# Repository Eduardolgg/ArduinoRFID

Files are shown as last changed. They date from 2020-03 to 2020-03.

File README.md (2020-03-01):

# ArduinoRFID
RFID authentication with Arduino.

# Domoticz

## Configuration

1. Set a static IP for the ESP-01s on your router.

2. Create the user variables rfid_id y rfid_ids_valid.
* rfid_id will contain the last tag sent to Domoticz.
* rfid_ids_valid will contain all valid tags.

3 Create the scripts using those found in the Domoticz_scripts directory, replace in the scripts the static IP associated with your wifi module.

## Add a new Tag

1. Scan the tag.

2. Go to Domoticz log and copy the ID.

3. Enter it in the user variable rfid_ids_valid by separating each Id by : (Ej: IDTAG1:IDTAG2:...).

# Arduino

1. Remember to replace the Domoticz IP and the user variable ID rfid_id in the code.

2. Flash Arduino and ESP-01s

3. Make the circuit using the included schemes

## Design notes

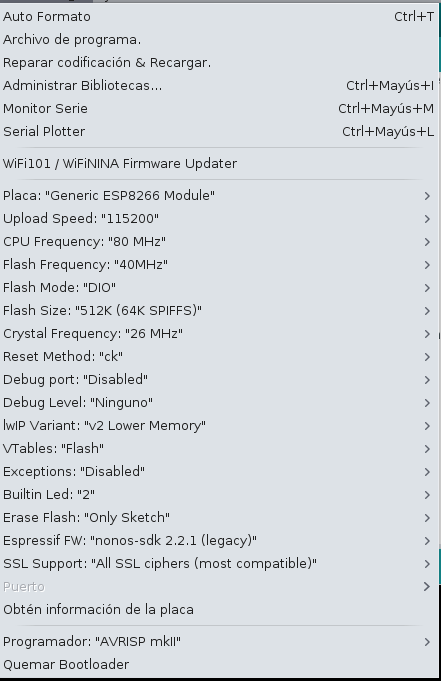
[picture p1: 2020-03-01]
ArduinoIDE_config.png

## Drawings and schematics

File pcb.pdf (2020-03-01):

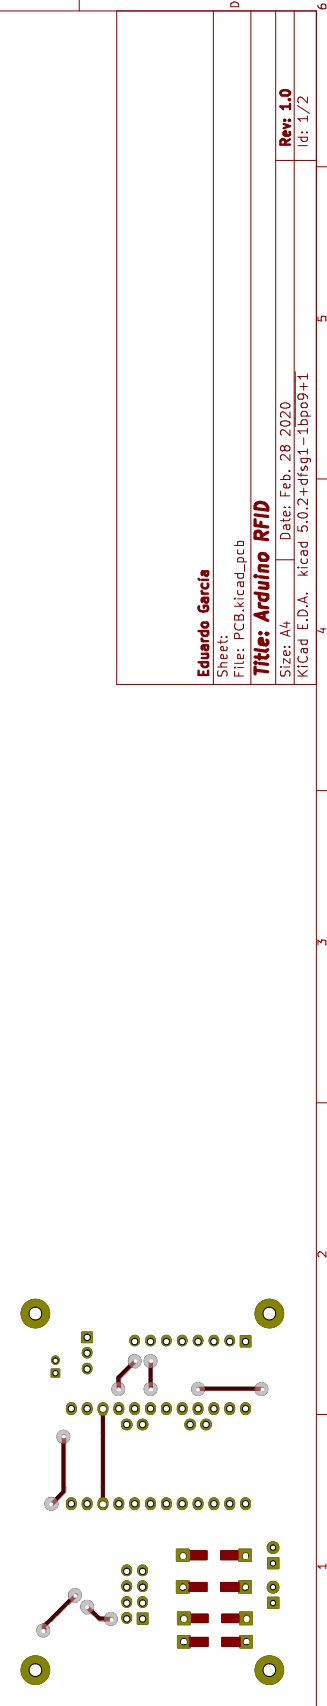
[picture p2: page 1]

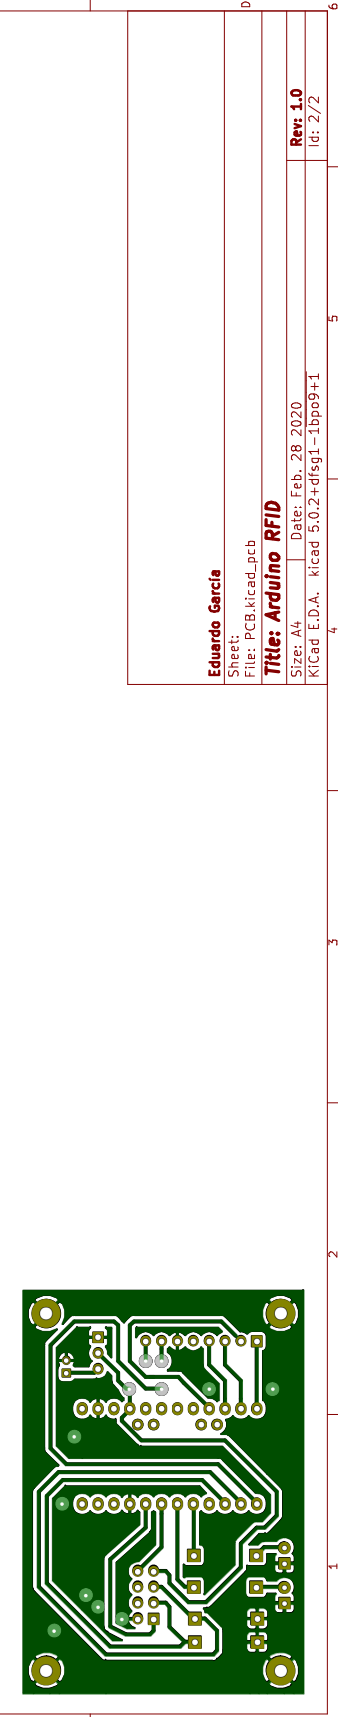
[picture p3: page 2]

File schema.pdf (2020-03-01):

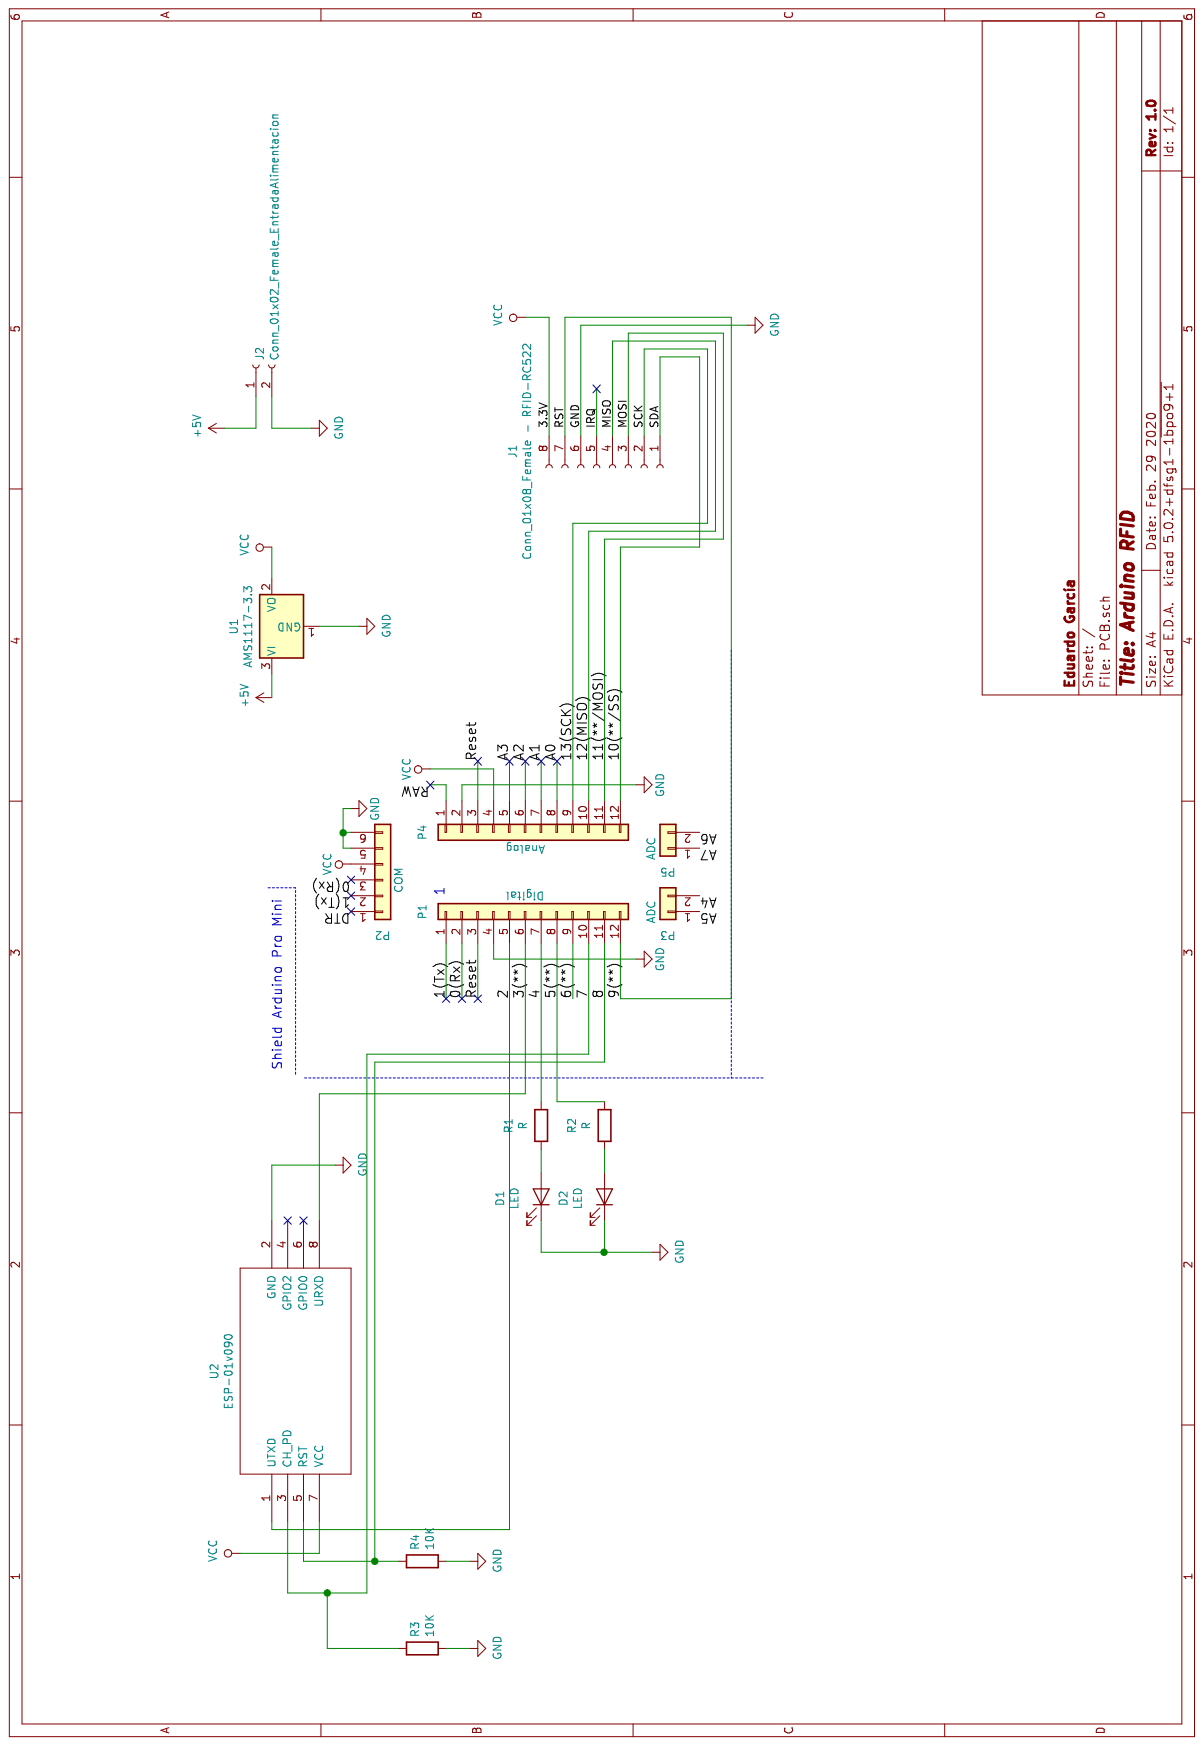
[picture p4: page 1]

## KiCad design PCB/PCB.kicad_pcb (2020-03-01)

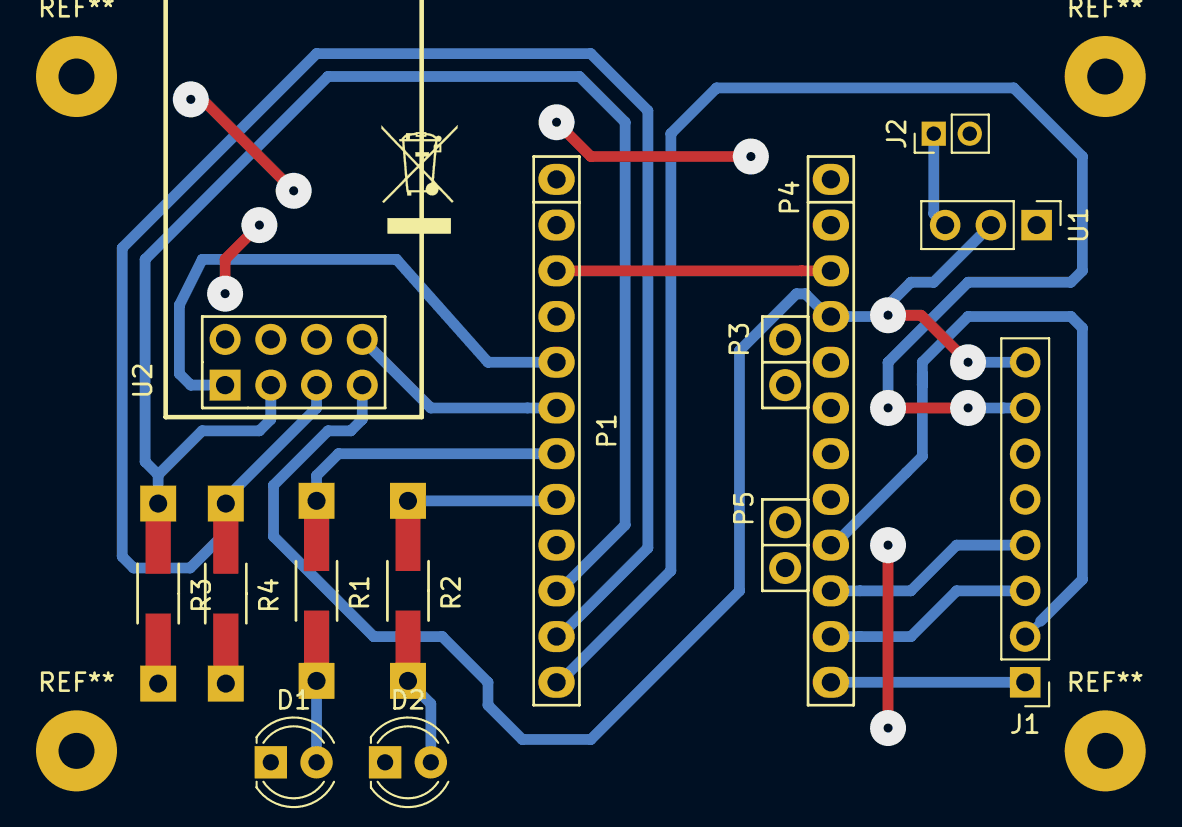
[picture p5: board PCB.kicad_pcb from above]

Board: 2 copper layers, 14 parts (0 on the bottom side), 17 nets.

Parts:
D1, D2: LED; LED_D4.0mm
J1: Conn_01x08_Female - RFID-RC522; Socket_Strip_Straight_1x08_Pitch2.54mm
J2: Conn_01x02_Female_EntradaAlimentacion; Socket_Strip_Straight_1x02_Pitch2.00mm
P1: Digital; Socket_Strip_Arduino_1x12
P3, P5: ADC; Socket_Strip_Arduino_1x02
P4: Analog; Socket_Strip_Arduino_1x12
R1, R2: R; Resistor_SMD+THTuniversal_1206_RM10_HandSoldering
R3, R4: 10K; Resistor_SMD+THTuniversal_1206_RM10_HandSoldering
U1: AMS1117-3.3; Socket_Strip_Straight_1x03_Pitch2.54mm
U2: ESP-01v090; ESP-01

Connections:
+5V: J2.1, U1.3
/2: P1.5, U2.1
/3(**): P1.6, U2.8
/4: P1.7, R1.1
/5(**): P1.8, R2.1
/7: P1.10, R3.1, U2.3
/8: P1.11, R4.1, U2.5
/9(**): J1.7, P1.12
/10(**/SS): J1.1, P4.12
/11(**/MOSI): J1.3, P4.11
/12(MISO): J1.4, P4.10
/13(SCK): J1.2, P4.9
/Reset: P1.3, P4.3
GND: D1.1, D2.1, J1.6, J2.2, P1.4, P4.2, R3.2, R4.2, U1.1, U2.2
unnamed: D1.2, R1.2
unnamed: D2.2, R2.2
VCC: J1.8, P4.4, U1.2, U2.7

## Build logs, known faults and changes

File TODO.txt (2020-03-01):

* HTTPS.
* Autentication.
* Change security status to Arm with tag.
* Battery.
* Accept multiple RFID modules
* Replace Domoticz user variables, create a new hardware in Domoticz.

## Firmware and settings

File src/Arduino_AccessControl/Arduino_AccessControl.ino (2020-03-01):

/*
 * This program is distributed in the hope that it will be useful,
 * but WITHOUT ANY WARRANTY.
 */


/*
   Typical pin layout used:
   -----------------------------------------------------------------------------------------
               MFRC522      Arduino       Arduino   Arduino  Arduino    Arduino          Arduino
               Reader/PCD   Uno/101       Mega      Nano v3  Pro Mini   Leonardo/Micro   Pro Micro
   Signal      Pin          Pin           Pin       Pin      Pin        Pin              Pin
   -----------------------------------------------------------------------------------------
   RST/Reset   RST          9             5         D9       D9         RESET/ICSP-5     RST
   SPI SS      SDA(SS)      10            53        D10      D10        10               10
   SPI MOSI    MOSI         11 / ICSP-4   51        D11      D11        ICSP-4           16
   SPI MISO    MISO         12 / ICSP-1   50        D12      D12        ICSP-1           14
   SPI SCK     SCK          13 / ICSP-3   52        D13      D13        ICSP-3           15
*/

#include <SPI.h>                // RC522 Module uses SPI protocol
#include <MFRC522.h>            // Library for Mifare RC522 Devices
#include <SoftwareSerial.h>
SoftwareSerial softSerial(2,3); // RX, TX
String inputString = "";        // A String to hold incoming data
bool stringComplete = false;    // whether the string is complete

const uint32_t baud = 9600;

#define ARM_LED_PIN 4
#define DISARM_LED_PIN 5

#define RESET_WIFI_PIN 8
#define ENABLE_WIFI_PIN 7

#define UNDEFINED 0
#define ARM 1
#define DISARM 2
int segMode = UNDEFINED; // Alarm status Armed/Disarmed.

uint8_t successRead;     // Variable integer to keep if we have Successful Read from Reader

byte readCard[4];        // Stores scanned ID read from RFID Module
String tag;              // Stores scanned ID read from RFID Module as String

// Create MFRC522 instance.
#define SS_PIN 10
#define RST_PIN 9
MFRC522 mfrc522(SS_PIN, RST_PIN);

///////////////////////////////////////// Setup ///////////////////////////////////
void setup() {

  // Pin config;
  pinMode(ARM_LED_PIN, OUTPUT);
  pinMode(DISARM_LED_PIN, OUTPUT);
  pinMode(RESET_WIFI_PIN, OUTPUT);
  pinMode(ENABLE_WIFI_PIN, OUTPUT);

  // Initial led mode;
  digitalWrite(ENABLE_WIFI_PIN, LOW);
  digitalWrite(RESET_WIFI_PIN, LOW);
  digitalWrite(ARM_LED_PIN, LOW);  
  digitalWrite(DISARM_LED_PIN, LOW);


  //Protocol Configuration
  Serial.begin(baud);      // Initialize serial communications with PC
  softSerial.begin(baud);  // Inicializs serial cominications with ESP-01s
  SPI.begin();             // MFRC522 Hardware uses SPI protocol
  mfrc522.PCD_Init();      // Initialize MFRC522 Hardware

  //If you set Antenna Gain to Max it will increase reading distance
  //mfrc522.PCD_SetAntennaGain(mfrc522.RxGain_max);

  Serial.println(F("Access Control Example v0.1"));   // For debugging purposes
  ShowReaderDetails();  // Show details of PCD - MFRC522 Card Reader details

  Serial.println(F("Waiting for Wifi module"));  
  digitalWrite(ENABLE_WIFI_PIN, HIGH);
  digitalWrite(RESET_WIFI_PIN, HIGH);
  while(!stringComplete) {
    leerComando();
    if (stringComplete) {
      if (inputString.indexOf("Wifi module started") >= 0)
        goto WifiConected;
      Serial.println(inputString);
      inputString = "";
      stringComplete = false;
    }
    Serial.print(".");
  }
WifiConected:
  Serial.println(inputString);
  inputString = "";
  stringComplete = false;
  // Tell wifi module get security status.
  softSerial.write("GetSecurityStatus\n");

  Serial.println(F("-------------------"));
  Serial.println(F("Everything is ready"));
  Serial.println(F("Waiting PICCs to be scanned"));
}


///////////////////////////////////////// Main Loop ///////////////////////////////////
void loop () {
  do {
    successRead = getID();  // sets successRead to 1 when we get read from reader otherwise 0    
    setStatusLeds();
    leerComando();
    if (stringComplete) {
      ejecutarComando(inputString);
      inputString = "";
      stringComplete = false;
    }
  } while (!successRead);   //the program will not go further while you are not getting a successful read
  sendTag();
}

void sendTag() {
  softSerial.write(String(tag + "\n").c_str());
}

void leerComando() {
  while (softSerial.available()) {
    // get the new byte:
    char inChar = (char)softSerial.read();
    // if the incoming character is a newline, set a flag so the main loop can
    // do something about it:
    if (inChar == '\n')
      stringComplete = true;
    else
      // add it to the inputString: I don't want a \n at end.
      inputString += inChar;
  }
}

void ejecutarComando(String comando) {
  if (comando == String("Disarm")) {
    segMode = DISARM;
  } else if (comando == String("Armed")) {
    segMode = ARM;
  } else
    Serial.write(String(comando + "\n").c_str());
}

void setStatusLeds() {
  if (segMode == DISARM) {
    digitalWrite(DISARM_LED_PIN, HIGH);
    digitalWrite(ARM_LED_PIN, LOW);
  } else if (segMode == ARM) {
    digitalWrite(DISARM_LED_PIN, LOW);
    digitalWrite(ARM_LED_PIN, HIGH);
  } else {
    digitalWrite(DISARM_LED_PIN, HIGH);
    digitalWrite(ARM_LED_PIN, HIGH);
  }
}

///////////////////////////////////////// Get PICC's UID ///////////////////////////////////
uint8_t getID() {
  // Getting ready for Reading PICCs
  if ( ! mfrc522.PICC_IsNewCardPresent()) { //If a new PICC placed to RFID reader continue
    return 0;
  }
  if ( ! mfrc522.PICC_ReadCardSerial()) {   //Since a PICC placed get Serial and continue
    return 0;
  }
  // There are Mifare PICCs which have 4 byte or 7 byte UID care if you use 7 byte PICC
  // I think we should assume every PICC as they have 4 byte UID
  // Until we support 7 byte PICCs
  Serial.println(F("Scanned PICC's UID:"));
  for ( uint8_t i = 0; i < 4; i++) {  //
    readCard[i] = mfrc522.uid.uidByte[i];
    Serial.print(readCard[i], HEX);
  }
  Serial.println("");
  mfrc522.PICC_HaltA(); // Stop reading

  char str[32] = "";
  array_to_string(readCard, 4, str);
  tag = String(str);

  return 1;
}

void ShowReaderDetails() {
  // Get the MFRC522 software version
  byte v = mfrc522.PCD_ReadRegister(mfrc522.VersionReg);
  Serial.print(F("MFRC522 Software Version: 0x"));
  Serial.print(v, HEX);
  if (v == 0x91)
    Serial.print(F(" = v1.0"));
  else if (v == 0x92)
    Serial.print(F(" = v2.0"));
  else
    Serial.print(F(" (unknown),probably a chinese clone?"));
  Serial.println("");
  // When 0x00 or 0xFF is returned, communication probably failed
  if ((v == 0x00) || (v == 0xFF)) {
    Serial.println(F("WARNING: Communication failure, is the MFRC522 properly connected?"));
    Serial.println(F("SYSTEM HALTED: Check connections."));
    while (true); // do not go further
  }
}

void array_to_string(byte array[], unsigned int len, char buffer[])
{
    for (unsigned int i = 0; i < len; i++)
    {
        byte nib1 = (array[i] >> 4) & 0x0F;
        byte nib2 = (array[i] >> 0) & 0x0F;
        buffer[i*2+0] = nib1  < 0xA ? '0' + nib1  : 'A' + nib1  - 0xA;
        buffer[i*2+1] = nib2  < 0xA ? '0' + nib2  : 'A' + nib2  - 0xA;
    }
    buffer[len*2] = '\0';
}

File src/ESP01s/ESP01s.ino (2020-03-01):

/*
 * This program is distributed in the hope that it will be useful,
 * but WITHOUT ANY WARRANTY.
 */


#include <ESP8266WiFi.h>
#include <ESP8266WiFiMulti.h>
#include <WiFiClient.h>
#include <ESP8266WebServer.h>
#include <ESP8266mDNS.h>
#include <ESP8266HTTPClient.h>

#ifndef STASSID
#define STASSID "Your_wifi_SSID_here"
#define STAPSK  "Your_wifi_password_here"
#endif

const uint32_t baud = 9600;

const char* ssid = STASSID;
const char* password = STAPSK;

ESP8266WebServer server(80);
ESP8266WiFiMulti WiFiMulti;

String inputString = "";         // A String to hold incoming data
bool stringComplete = false;     // whether the string is complete

void handleRoot() {
  server.send(200, "text/plain", "ok");
  if (server.arg("command").equals("Disarm"))
    Serial.printf("Disarm\n");
  if (server.arg("command").equals("Armed"))
    Serial.printf("Armed\n");
}

void handleNotFound() {
  String message = "File Not Found\n\n";
  message += "URI: ";
  message += server.uri();
  message += "\nMethod: ";
  message += (server.method() == HTTP_GET) ? "GET" : "POST";
  message += "\nArguments: ";
  message += server.args();
  message += "\n";
  for (uint8_t i = 0; i < server.args(); i++) {
    message += " " + server.argName(i) + ": " + server.arg(i) + "\n";
  }
  server.send(404, "text/plain", message);
}

void setup(void) {
  Serial.begin(baud);
  WiFi.mode(WIFI_STA);
  //WiFi.begin(ssid, password);
  WiFiMulti.addAP(ssid, password);
  Serial.println("");

  // Wait for connection
  while (WiFiMulti.run() != WL_CONNECTED) {
    delay(500);
    Serial.print(".");
  }
  Serial.println("");
  Serial.print("Connected to ");
  Serial.println(ssid);
  Serial.print("IP address: ");
  Serial.println(WiFi.localIP());

  if (MDNS.begin("esp8266")) {
    Serial.println("MDNS responder started");
  }

  server.on("/", handleRoot);

  /*server.on("/inline", []() {
    server.send(200, "text/plain", "this works as well");
  });*/

  server.onNotFound(handleNotFound);

  server.begin();
  Serial.println("Wifi module started");
}

void leerComando() {
  while (Serial.available()) {
    // Get the new byte:
    char inChar = (char)Serial.read();    
    // Serial.printf("leerComando: leido %c comando: %s\n", inChar, inputString.c_str());
    // if the incoming character is a newline, set a flag so the main loop can
    // do something about it:
    if (inChar == '\n')
      stringComplete = true;
    else
      // add it to the inputString: I don't want a \n at end.
      inputString += inChar;
  }
}

/**
 * Send the RFID Tag detected to verify in the control unit.
 */
void ejecutarComando(String command) {
  HTTPClient http;
  WiFiClient client;
  String url = "http://192.168.xxx.xxx/json.htm?type=command&param=updateuservariable&idx=18&vname=rfid_id&vtype=2&vvalue=";
  url.concat(command);
  url.trim();

  if (WiFiMulti.run() != WL_CONNECTED) {
    Serial.printf("Waiting for wifi to reconnect");
    while ((WiFiMulti.run() != WL_CONNECTED))
      Serial.print(".");
    Serial.println("");
  }

  Serial.printf("Run command: dest url: %s\n", url.c_str());
  if (http.begin(client, url)) {
    int httpCode = http.GET();
    if (httpCode > 0) {
      if (httpCode == HTTP_CODE_OK || httpCode == HTTP_CODE_MOVED_PERMANENTLY)
        Serial.printf("ejecutarComando: Tag %s send success \n", command.c_str());
      else {
        Serial.printf("ejecutarComando: Call error %i\n  response: ", httpCode);
        //String payload = http.getString();
        //Serial.println(payload);
      }
    } else
      Serial.printf("ejecutarComando: [HTTP] GET... failed, error: %s\n", http.errorToString(httpCode).c_str()); 
    http.end();
  } else
    Serial.printf("ejecutarComando: [HTTP} Unable to connect\n");
}

void loop(void) {
  server.handleClient();
  MDNS.update();
  leerComando();
  if (stringComplete) {
    ejecutarComando(inputString);
    inputString = "";
    stringComplete = false;
  }
}
